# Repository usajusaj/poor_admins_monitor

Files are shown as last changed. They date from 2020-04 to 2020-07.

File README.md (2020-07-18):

# Poor Admin's Monitor
For my fellow sysadmins who would like to be responsible and monitor server room temperature but professional monitor appliances are too expensive.

The plan here is pretty simple, all you need is:
- Some sort of x86/ARM capable single-board computer like [RaspberryPI](https://www.raspberrypi.org/) with GPIO pins
- A few components, the star of the show is 1-Wire temperature sensor like [MAX31820](https://datasheets.maximintegrated.com/en/ds/MAX31820.pdf)
- Basic soldering experience

## Design
1-Wire ambient temperature sensing devices are cheap (~$1CAD/each), easy to control (1-wire protocol drivers are readily available) and one can chain a lot of them on a single wire. I'm using UTP since every server room has plenty spare.

I'm chose a standalone C++ web framework to avoid running the bloat that are NGINX/Apache2 + Django/PHP/... on an rpi. But deep down I just wanted to try something new.

## Building
- Download/clone Drogon: https://github.com/an-tao/drogon
- Follow its installation steps, before running cmake add this line to drogon's CMakeList.txt to fix linking errors on RaspberryPI
```cmake
target_link_libraries(${PROJECT_NAME} PUBLIC atomic)
```
- Install drogon
- Download/clone this code, do usual
```shell script
$ mkdir build
$ cd build
$ cmake ..
$ make
```

## Running
- initialize database
```shell script
sqlite3 database.db
> .read sqlite3.sql
```
- put [poll_devices.py](poll_devices.py) in a crontab at arbitrary interval, ie every minute:
```shell script
* * * * *       /home/pi/poor_admins_monitor/poll_devices.py /home/pi/poor_admins_monitor/database.db
``` 

- while database is filling up with first data, rename [config.json.template](config.json.template) to config.json and adjust settings to your liking
- run web server with
```shell script
./poor_admins_monitor
``` 

- Point browser to:
  - `http://host:port/api/v1/device/list`
  - `http://host:port/api/v1/device/get/1`
  - `http://host:port/api/v1/device/get/1/history`
  
## Future features
- Advertise service over avahi
- Configuration script to assign each device a verbose name and location
- Add systemd timer example file for a <1m polling interval (impossible in cron)

## Thanks to
- [Drogon](https://github.com/an-tao/drogon) for an awesome C++ web framework
- [Pure.css](https://purecss.io/) for an elegant lightweight css scaffold
- [Chart.js](https://www.chartjs.org/) for slick charts

## Gallery
### Main page with graphed temperatures
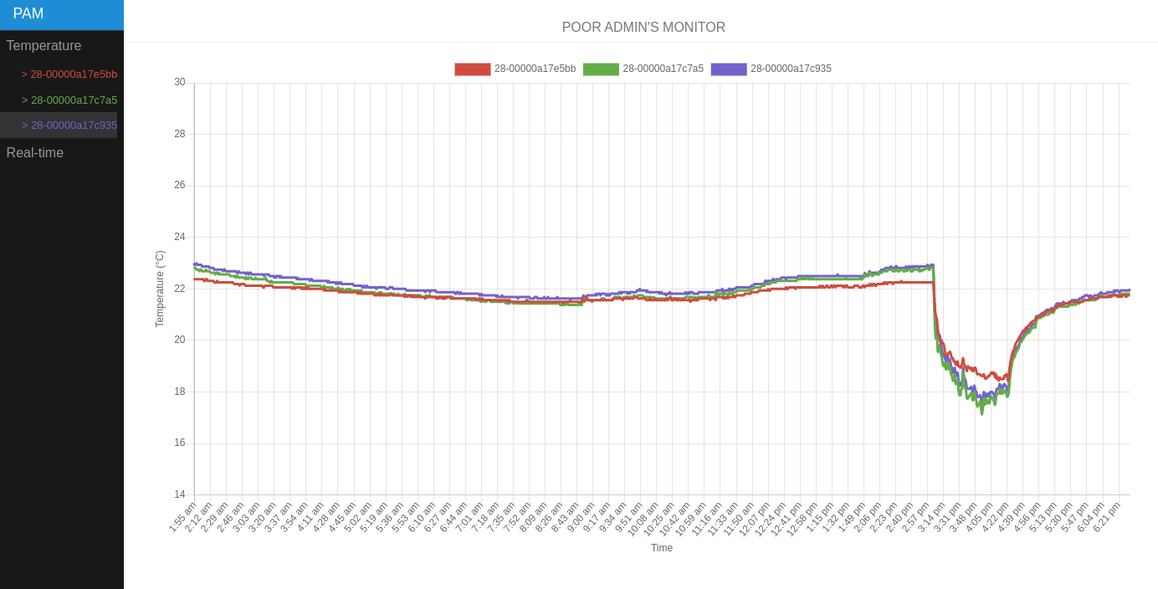
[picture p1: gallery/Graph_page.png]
Dashboard


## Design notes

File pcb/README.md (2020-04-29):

# Printed circuit board (PCB) designs
Schemes for convenient small pcb's of the two main components of this project. 
Software used to create and edit this is [KiCad](https://www.kicad-pcb.org/).

Each module can be also soldered by hand on a proto-board or even directly on 
the connector pins, but using a custom pcb is easier.

## [pam_main_module](pam_main_module)
KiCad project for the main module that connects to a single-board device (RPi) 
GPIO pins and then uses a common UTP over RJ45 (aka ethernet) to connect 1-Wire
thermal sensors. Pins used/needed are: +3.3V, GROUND and DATA (digital I/O).
Board is designed with 3 RJ45 connectors so you can route the cables in multiple 
directions, but only one is required to be soldered in place.

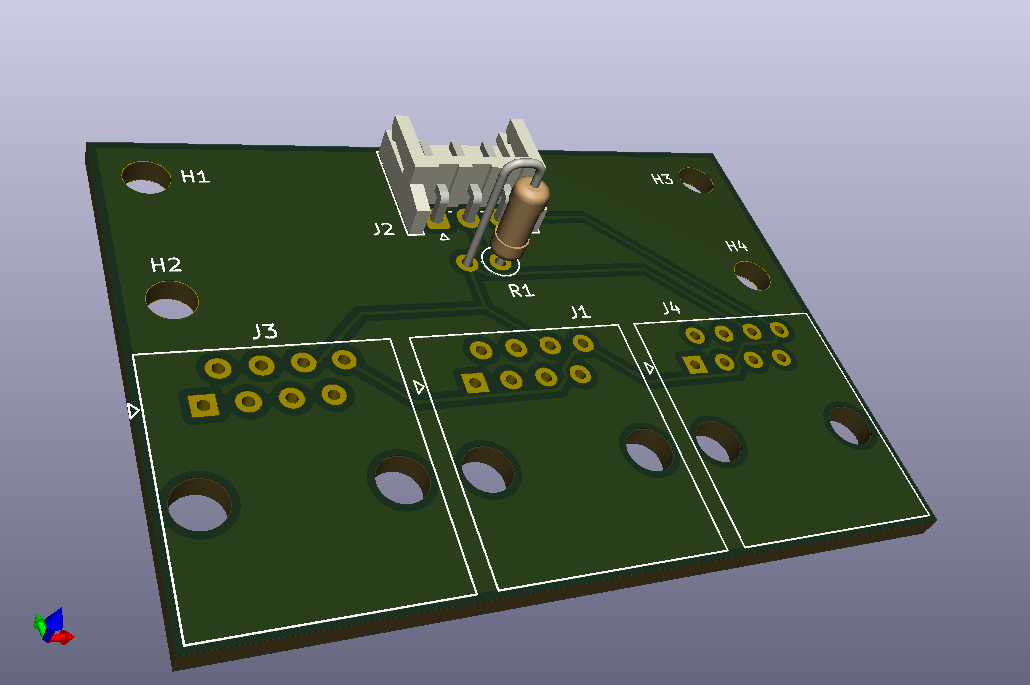
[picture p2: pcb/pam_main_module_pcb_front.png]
Main module picture


## [pam_chain_module](pam_chain_module)
KiCad project for the chain module with thermal sensor. This module features 
2 RJ45 connectors for daisy-chaining them in series. Thermal sensor is soldered 
on the opposite side so that it's not sandwiched between the two RJ45 casings for more
accurate readings.

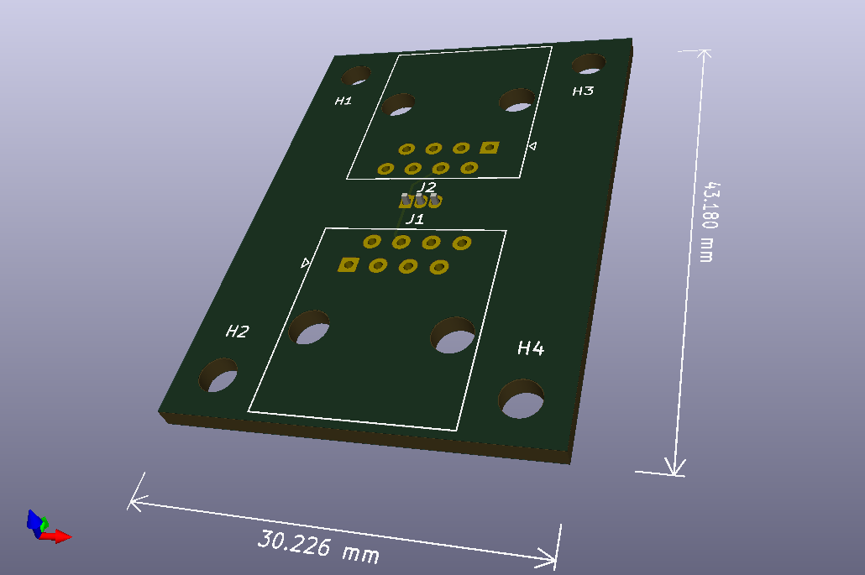
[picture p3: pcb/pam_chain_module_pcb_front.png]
Chain module picture


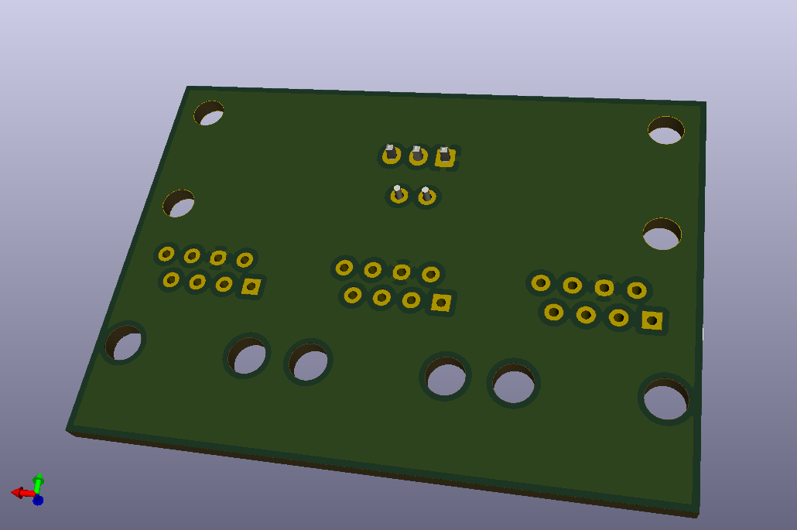
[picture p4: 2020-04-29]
pcb/pam_main_module_pcb_back.png

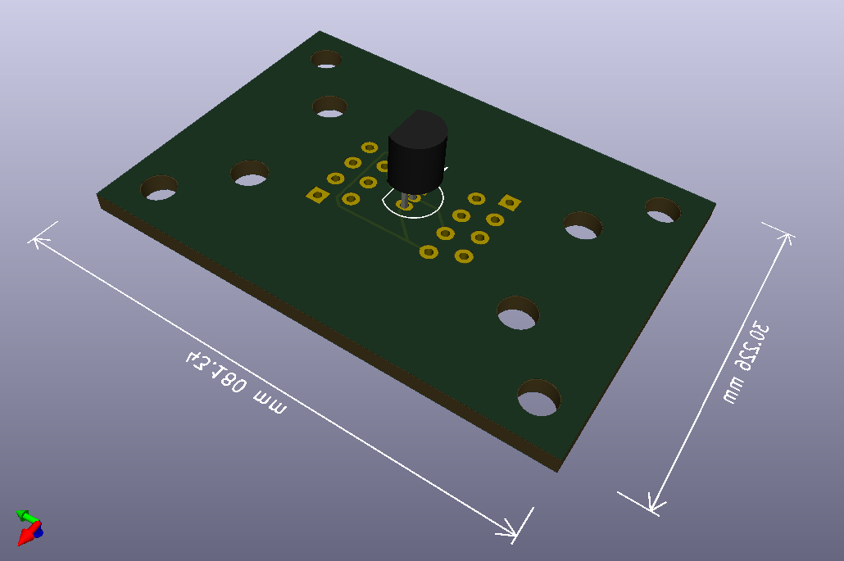
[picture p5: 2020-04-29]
pcb/pam_chain_module_pcb_back.png

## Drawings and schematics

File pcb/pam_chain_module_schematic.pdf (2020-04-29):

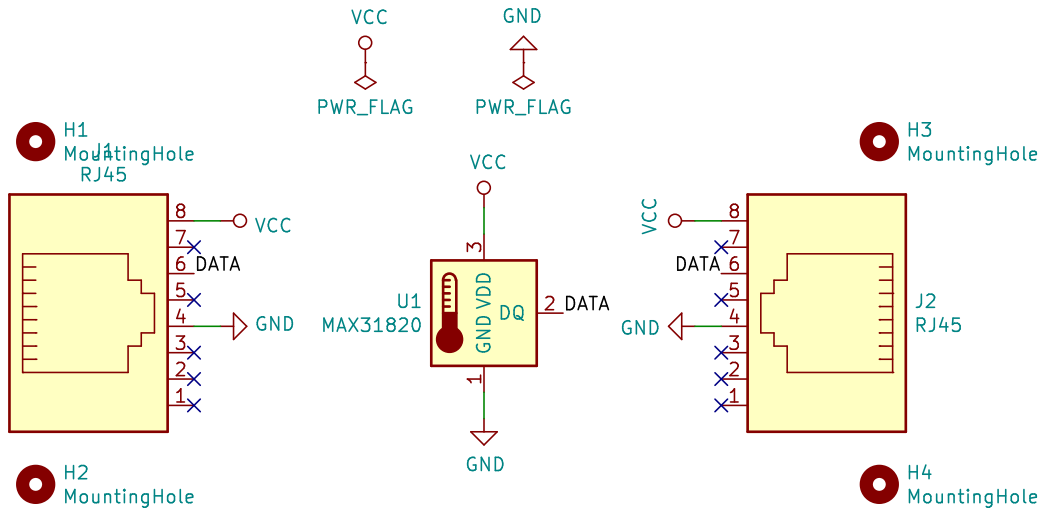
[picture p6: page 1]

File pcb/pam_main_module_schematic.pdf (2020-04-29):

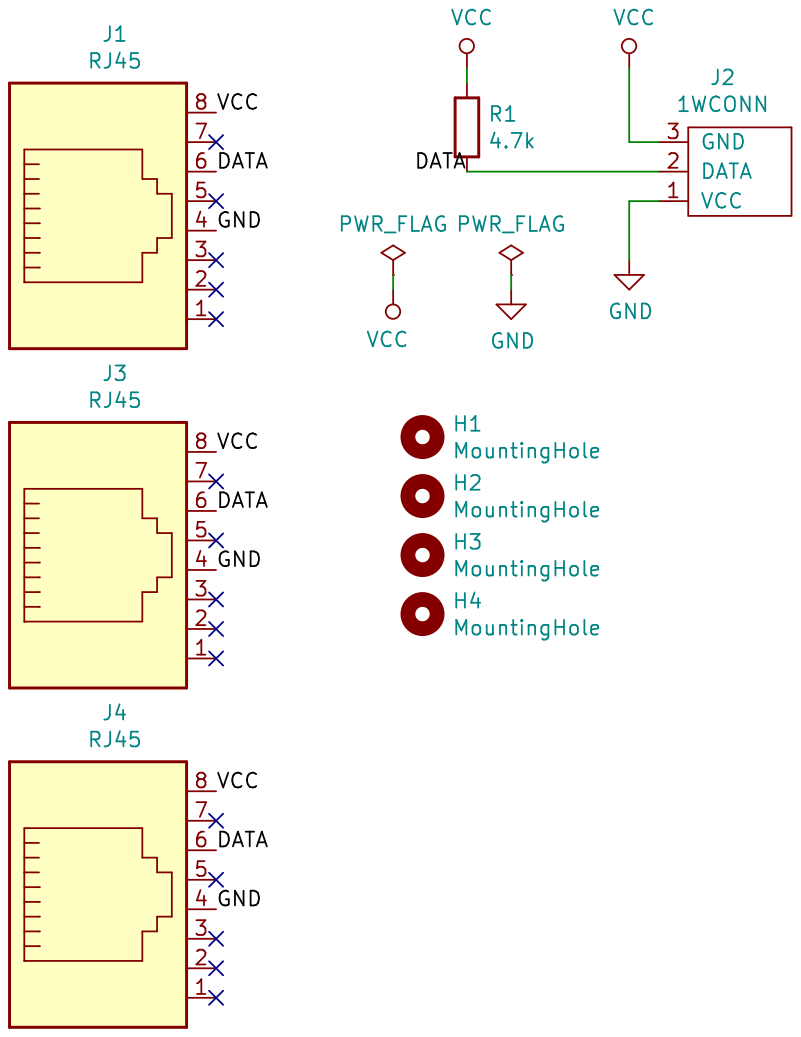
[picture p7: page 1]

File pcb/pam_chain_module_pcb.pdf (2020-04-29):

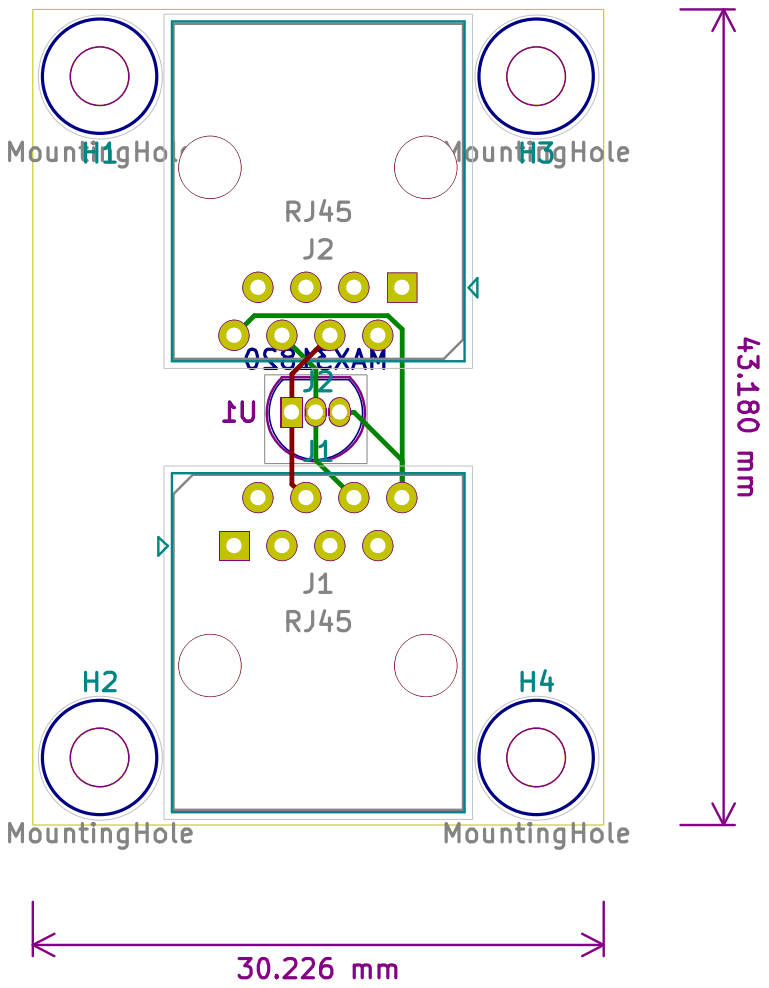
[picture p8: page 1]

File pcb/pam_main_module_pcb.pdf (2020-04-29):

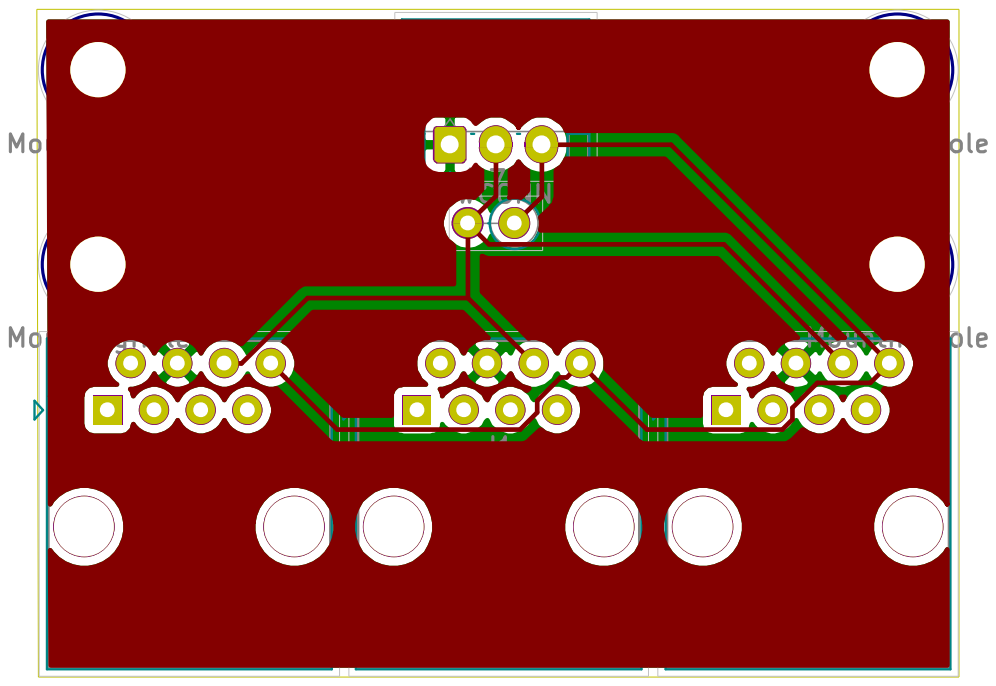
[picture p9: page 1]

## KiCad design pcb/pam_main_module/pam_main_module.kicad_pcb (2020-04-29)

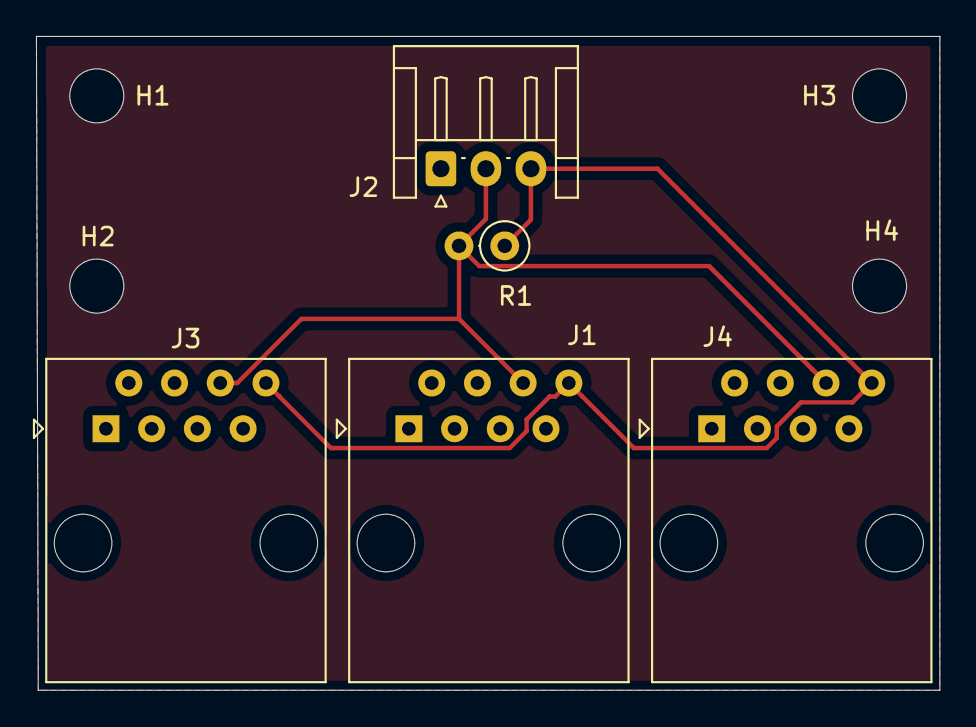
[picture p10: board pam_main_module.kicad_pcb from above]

Board: 2 copper layers, 50.2 x 36.3 mm, 9 parts (0 on the bottom side), 3 nets.

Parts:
H1, H2, H3, H4: MountingHole; MountingHole_3mm
J1, J3, J4: RJ45; RJ45_Amphenol_54602-x08_Horizontal
J2: 1WCONN; JST_EH_S3B-EH_1x03_P2.50mm_Horizontal
R1: 4.7k; R_Axial_DIN0207_L6.3mm_D2.5mm_P2.54mm_Vertical

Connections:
/DATA: J1.6, J2.2, J3.6, J4.6, R1.2
GND: J1.4, J2.1, J3.4, J4.4
VCC: J1.8, J2.3, J3.8, J4.8, R1.1

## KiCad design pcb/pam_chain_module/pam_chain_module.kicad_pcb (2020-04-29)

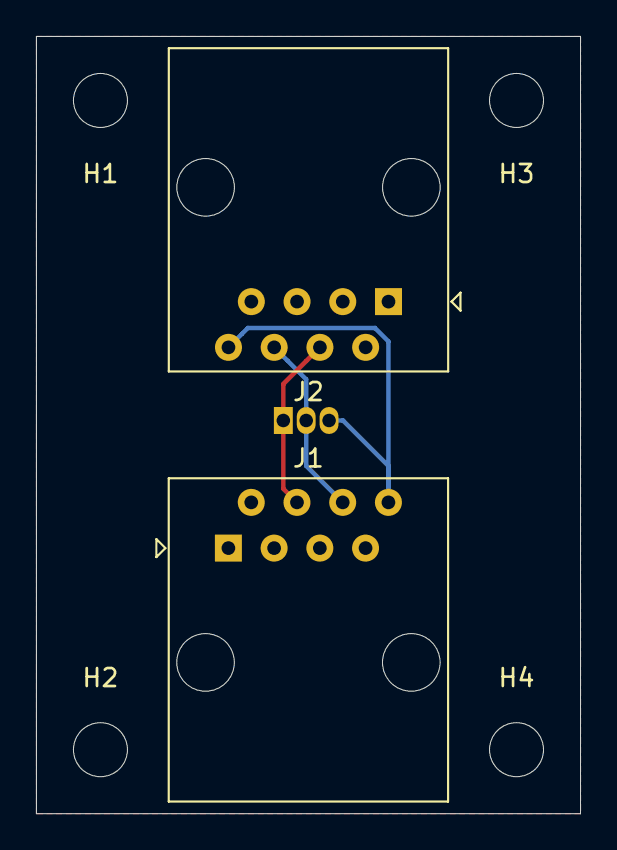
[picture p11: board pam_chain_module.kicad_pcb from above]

Board: 2 copper layers, 30.2 x 43.2 mm, 7 parts (1 on the bottom side), 3 nets.

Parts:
H1, H2, H3, H4: MountingHole; MountingHole_3mm
J1, J2: RJ45; RJ45_Amphenol_54602-x08_Horizontal
U1: MAX31820; TO-92_Inline

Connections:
/DATA: J1.6, J2.6, U1.2
GND: J1.4, J2.4, U1.1
VCC: J1.8, J2.8, U1.3

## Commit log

2020-04-24 Added device history API, updated README.md
2020-04-24 Fill reading table using trigger instead of inserts
2020-04-29 Added pcb designs for main and link modules
    [pam_chain_module.kicad_pcb, pam_chain_module.sch, pam_main_module.kicad_pcb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]
2020-04-29 Added readme for pcb designs
2020-04-30 Have a consistent device ordering
2020-10-01 Added missing INDEX on reading (device)
2021-02-10 Update poll_devices.py
    Proper handling of verbose_name, even on new devices
